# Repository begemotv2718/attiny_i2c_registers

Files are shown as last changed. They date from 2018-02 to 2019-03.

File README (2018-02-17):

Implementation of smbus i2c slave with registers on attiny mcu. 

Write register: view from master (slave replies in brackets)
START Addr Wr [ACK] RegNum [ACK] Value [ACK] STOP

Read register: view from master

START Addr Wr [ACK] RegNum [ACK] START Addr Rd [RegValue] NAK STOP

Seems to work for slow transfers (<5kHz).

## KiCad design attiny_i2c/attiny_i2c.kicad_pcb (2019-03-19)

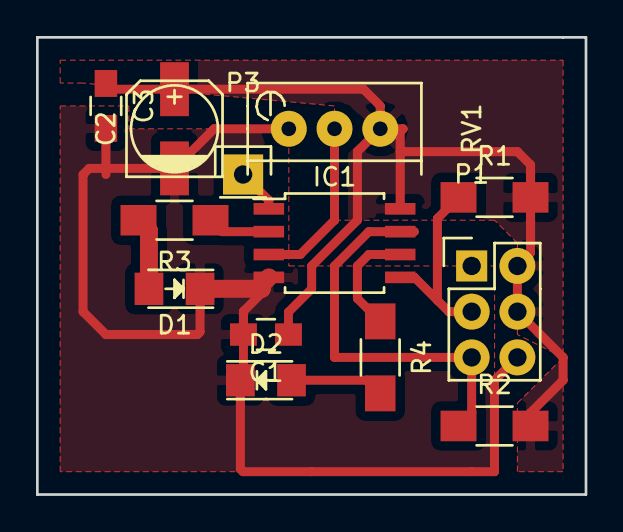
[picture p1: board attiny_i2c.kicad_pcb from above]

Board: 2 copper layers, 30.5 x 25.4 mm, 13 parts (0 on the bottom side), 10 nets.

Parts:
C1, C3: C_Small; C_0805_HandSoldering
C2: CP_Small; c_elec_5x5.8
D1, D2: Led_Small; LED-1206
IC1: ATTINY25-S; SOIJ-8_5.3x5.3mm_Pitch1.27mm
P1: CONN_02X03; Pin_Header_Straight_2x03
P3: CONN_01X01; Pin_Header_Straight_1x01
R1, R2, R3, R4: R; R_1206_HandSoldering
RV1: POT; Potentiometer_Bourns_3296W_3-8Zoll_Inline_ScrewUp

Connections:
+5V: C1.1, C2.1, C3.1, IC1.8, P1.2, P1.4, R1.2, R2.2, RV1.3
GND: C1.2, C2.2, C3.2, D1.1, D2.1, IC1.4, P1.6, RV1.1
I2C_SCL: IC1.7, P1.5, R2.1
I2C_SDA: IC1.5, P1.3, R1.1
LED1: IC1.2, R3.1
LED2: IC1.6, R4.1
unnamed: D1.2, R3.2
unnamed: D2.2, R4.2
PRG_RST: IC1.1, P3.1
VREG: IC1.3, RV1.2

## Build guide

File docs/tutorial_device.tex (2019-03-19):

\documentclass{article}
\usepackage{graphicx}
\begin{document}
\title{Tutorial I$^2$C device}
\maketitle
\section{Device pinout}
The device has 4 pins connected as described in picture~(\ref{l-pinout}).
\begin{figure}[h]
  
  \caption{Device pinout. $V_{cc}$ pin is supply voltage. GND pin should be connected to the ground. Two other pins are for I$^2$C communication}\label{l-pinout}
\end{figure}
\section{Device communication protocol}
\subsection{I$^2$C protocol description}
The device communicates via two-wire I$^2$C interface as a slave device. The device use 7-bit addressing mode. The data rate in the standard mode is limited to 10kbps. The default (factory) device slave address is 0x33 (8-bit address 0x66 for writing 0x67 for reading). 

The device include pull-up resistors between $V_{cc}$ pin and I$^2$C lines.

All bus transactions begin with the master device issuing the start sequence followed by the slave address byte. The address byte contains the slave address: the upper 7-bits is the 7-bit slave address, followed by one bit which is set to 1 if the operation is read and to 0 if the operation is write. At the 9-th clock pulse the receiving slave device will issue ACK (by pulling the SDA line low) or NACK. Following these bus events, the master will send out bytes for a write operation, or the slave will clock out data with the read operation.All bus transactions are terminated with the master issuing a stop sequence. 

\subsection{SMBus protocol description}
The device use subset of SMBus protocol to transfer the values of its registers to the master device.
\subsubsection{Key to symbols}
\begin{tabular}{lll}
  S    & (1 bit) & Start bit\\
  P    & (1 bit) & Stop bit\\
  Rd/Wr & (1 bit) & Read/Write bit. Rd equals 1, Wr equals 0.\\
  A, NA & (1 bit) & Accept and reverse accept bit. \\
  Addr  & (7 bits)& I2C 7 bit address.\\
  Comm  & (8 bits)& Register(command) \\
  Data  & (8 bits)& A plain data byte. \\
  $[$...$]$  &         & Data send by slave as opposed to data send by master
\end{tabular}

\subsubsection{Reading a register}
The following sequence reads a single byte from the device register:

S Addr Wr [A] Comm [A] S Addr Rd [A] [Data] NA P

\subsection{Writing a register}
The following sequence writes a single byte to the device register:

S Addr Wr [A] Comm [A] Data [A] P

\subsubsection{Reading a block of registers}

\subsubsection{Writing a block of registers}

\section{Registers description}

\paragraph{Resistor readout register: address 0x03}
Contains value corresponding to the current position of resistor sensor. Value is in range 0..255. Read-only, write operations will be ignored.
\paragraph{Semi-random value register: address 0x05}
The value of this register is continuously updated. Suitable to getting semi-random numbers in the range 0..127.
Read-only, write operations will be ignored.
\paragraph{Identification register: address 0x06}
The value read from this register is always constant -- decimal 50.
Read-only, write operations will be ignored.
\paragraph{LED control register: address 0x07}
Writing non-zero value to this register switches LED on. Writing zero to this register swithches LED off. Reading from this register will give the status of the LED.
Read-write.

\end{document}

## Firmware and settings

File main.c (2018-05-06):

#include "usiTwiSlave.h"
#include <util/delay.h>
#include "softuart.h"
#include "adc.h"
#include <avr/wdt.h>

#define PIN_LED1 3

inline void send_hex_digit(uint8_t data)
{
  data = data&0x0f;
  if(data>0x9)
  {
    softuart_send(data-0xa+'a');
  }
  else
  {
    softuart_send(data+'0');
  }
}

inline void status_led(void)
{
  if(usiTwiReadRegister(0x07)>0)
  {
    PORTB |= (1<<PIN_LED1);
  }
  else
  {
    PORTB &= ~(1<<PIN_LED1);
  }
}

int main(void)
{
    uint8_t save_mcusr=MCUSR; 
    wdt_reset();
    MCUSR = 0x00;
    WDTCR |= (1<<WDCE)|(1<<WDE);// watchdog change enable
    WDTCR = 0x00;//watchdog disable
    //wdt_disable();
    
    softuart_init();
    _delay_ms(1);
    softuart_send(' ');

    send_hex_digit(save_mcusr>>4);
    send_hex_digit(save_mcusr&(0x0f));
    softuart_send('h');
    
    
    usiTwiSlaveInit(0x33);
    sei();
    initADC();
    DDRB |= (1<<PIN_LED1); //LED PIN


    while(1)
    {
      _delay_ms(1);
      status_led();
      //softuart_send('x');
    }
}

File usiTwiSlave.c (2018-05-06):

/********************************************************************************

USI TWI Slave driver.

Created by Donald R. Blake. donblake at worldnet.att.net
Adapted by Jochen Toppe, jochen.toppe at jtoee.com
Smbus registers: begemotv2718@gmail.com

---------------------------------------------------------------------------------

Created from Atmel source files for Application Note AVR312: Using the USI Module
as an I2C slave.

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
---------------------------------------------------------------------------------

Change Activity:

    Date       Description
   ------      -------------
  16 Mar 2007  Created.
  27 Mar 2007  Added support for ATtiny261, 461 and 861.
  26 Apr 2007  Fixed ACK of slave address on a read.
  04 Jul 2007  Fixed USISIF in ATtiny45 def
  12 Dev 2009  Added callback functions for data requests
  17 Feb 2017  Implementation of state machine for "register file"

********************************************************************************/

#ifndef TEST

/********************************************************************************
                                    includes
********************************************************************************/

#include <avr/io.h>
#include <avr/interrupt.h>

#include "usiTwiSlave.h"
#include "softuart.h"
//#include "../common/util.h"


/********************************************************************************
                            device dependent defines
********************************************************************************/

#if defined( __AVR_ATtiny2313__ )
#  define DDR_USI             DDRB
#  define PORT_USI            PORTB
#  define PIN_USI             PINB
#  define PORT_USI_SDA        PB5
#  define PORT_USI_SCL        PB7
#  define PIN_USI_SDA         PINB5
#  define PIN_USI_SCL         PINB7
#  define USI_START_COND_INT  USISIF
#  define USI_START_VECTOR    USI_START_vect
#  define USI_OVERFLOW_VECTOR USI_OVERFLOW_vect
#endif

#if defined( __AVR_ATtiny25__ ) | \
     defined( __AVR_ATtiny45__ ) | \
     defined( __AVR_ATtiny85__ )
#  define DDR_USI             DDRB
#  define PORT_USI            PORTB
#  define PIN_USI             PINB
#  define PORT_USI_SDA        PB0
#  define PORT_USI_SCL        PB2
#  define PIN_USI_SDA         PINB0
#  define PIN_USI_SCL         PINB2
#  define USI_START_COND_INT  USISIF
#  define USI_START_VECTOR    USI_START_vect
#  define USI_OVERFLOW_VECTOR USI_OVF_vect
#endif

#if defined( __AVR_ATtiny26__ )
#  define DDR_USI             DDRB
#  define PORT_USI            PORTB
#  define PIN_USI             PINB
#  define PORT_USI_SDA        PB0
#  define PORT_USI_SCL        PB2
#  define PIN_USI_SDA         PINB0
#  define PIN_USI_SCL         PINB2
#  define USI_START_COND_INT  USISIF
#  define USI_START_VECTOR    USI_STRT_vect
#  define USI_OVERFLOW_VECTOR USI_OVF_vect
#endif

#if defined( __AVR_ATtiny261__ ) | \
     defined( __AVR_ATtiny461__ ) | \
     defined( __AVR_ATtiny861__ )
#  define DDR_USI             DDRB
#  define PORT_USI            PORTB
#  define PIN_USI             PINB
#  define PORT_USI_SDA        PB0
#  define PORT_USI_SCL        PB2
#  define PIN_USI_SDA         PINB0
#  define PIN_USI_SCL         PINB2
#  define USI_START_COND_INT  USISIF
#  define USI_START_VECTOR    USI_START_vect
#  define USI_OVERFLOW_VECTOR USI_OVF_vect
#endif

#if defined( __AVR_ATmega165__ ) | \
     defined( __AVR_ATmega325__ ) | \
     defined( __AVR_ATmega3250__ ) | \
     defined( __AVR_ATmega645__ ) | \
     defined( __AVR_ATmega6450__ ) | \
     defined( __AVR_ATmega329__ ) | \
     defined( __AVR_ATmega3290__ )
#  define DDR_USI             DDRE
#  define PORT_USI            PORTE
#  define PIN_USI             PINE
#  define PORT_USI_SDA        PE5
#  define PORT_USI_SCL        PE4
#  define PIN_USI_SDA         PINE5
#  define PIN_USI_SCL         PINE4
#  define USI_START_COND_INT  USISIF
#  define USI_START_VECTOR    USI_START_vect
#  define USI_OVERFLOW_VECTOR USI_OVERFLOW_vect
#endif

#if defined( __AVR_ATmega169__ )
#  define DDR_USI             DDRE
#  define PORT_USI            PORTE
#  define PIN_USI             PINE
#  define PORT_USI_SDA        PE5
#  define PORT_USI_SCL        PE4
#  define PIN_USI_SDA         PINE5
#  define PIN_USI_SCL         PINE4
#  define USI_START_COND_INT  USISIF
#  define USI_START_VECTOR    USI_START_vect
#  define USI_OVERFLOW_VECTOR USI_OVERFLOW_vect
#endif



/********************************************************************************

                        functions implemented as macros

********************************************************************************/

#define SET_USI_TO_SEND_ACK( ) \
{ \
  /* prepare ACK */ \
  USIDR = 0; \
  /* set SDA as output */ \
  DDR_USI |= ( 1 << PORT_USI_SDA ); \
  /* clear all interrupt flags, except Start Cond */ \
  USISR = \
       ( 0 << USI_START_COND_INT ) | \
       ( 1 << USIOIF ) | ( 1 << USIPF ) | \
       ( 1 << USIDC )| \
       /* set USI counter to shift 1 bit */ \
       ( 0x0E << USICNT0 ); \
}

#define SET_USI_TO_READ_ACK( ) \
{ \
  /* set SDA as input */ \
  DDR_USI &= ~( 1 << PORT_USI_SDA ); \
  /* prepare ACK */ \
  USIDR = 0; \
  /* clear all interrupt flags, except Start Cond */ \
  USISR = \
       ( 0 << USI_START_COND_INT ) | \
       ( 1 << USIOIF ) | \
       ( 1 << USIPF ) | \
       ( 1 << USIDC ) | \
       /* set USI counter to shift 1 bit */ \
       ( 0x0E << USICNT0 ); \
}

#define SET_USI_TO_TWI_START_CONDITION_MODE( ) \
{ \
  USICR = \
       /* enable Start Condition Interrupt, disable Overflow Interrupt */ \
       ( 1 << USISIE ) | ( 0 << USIOIE ) | \
       /* set USI in Two-wire mode, no USI Counter overflow hold */ \
       ( 1 << USIWM1 ) | ( 0 << USIWM0 ) | \
       /* Shift Register Clock Source = External, positive edge */ \
       /* 4-Bit Counter Source = external, both edges */ \
       ( 1 << USICS1 ) | ( 0 << USICS0 ) | ( 0 << USICLK ) | \
       /* no toggle clock-port pin */ \
       ( 0 << USITC ); \
  USISR = \
        /* clear all interrupt flags, except Start Cond */ \
        ( 0 << USI_START_COND_INT ) | ( 1 << USIOIF ) | ( 1 << USIPF ) | \
        ( 1 << USIDC ) | ( 0x0 << USICNT0 ); \
}

#define SET_USI_TO_SEND_DATA( ) \
{ \
  /* set SDA as output */ \
  DDR_USI |=  ( 1 << PORT_USI_SDA ); \
  /* clear all interrupt flags, except Start Cond */ \
  USISR    =  \
       ( 0 << USI_START_COND_INT ) | ( 1 << USIOIF ) | ( 1 << USIPF ) | \
       ( 1 << USIDC) | \
       /* set USI to shift out 8 bits */ \
       ( 0x0 << USICNT0 ); \
}

#define SET_USI_TO_READ_DATA( ) \
{ \
  /* set SDA as input */ \
  DDR_USI &= ~( 1 << PORT_USI_SDA ); \
  /* clear all interrupt flags, except Start Cond */ \
  USISR    = \
       ( 0 << USI_START_COND_INT ) | ( 1 << USIOIF ) | \
       ( 1 << USIPF ) | ( 1 << USIDC ) | \
       /* set USI to shift out 8 bits */ \
       ( 0x0 << USICNT0 ); \
}
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

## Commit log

2018-02-17 Added ADC example
2018-05-05 More or less current schematics
    [attiny_i2c.kicad_pcb, attiny_i2c.sch]
2018-05-06 Current module version
2019-03-19 Modified pcb
    [attiny_i2c.kicad_pcb]
2019-03-19 Documentation for example device

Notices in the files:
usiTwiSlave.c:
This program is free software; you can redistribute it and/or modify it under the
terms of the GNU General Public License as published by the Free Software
